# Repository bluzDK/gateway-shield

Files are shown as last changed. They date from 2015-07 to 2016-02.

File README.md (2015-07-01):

<p align="center" >
Bluz
</p>

Bluz Gateway Shield Hardware Files
==========
Bluz is a Development Kit (DK) that implements the Wiring language and talks to the [Particle](https://www.particle.io/) cloud through Bluetooth Low Energy. It can be accessed through a REST API and programmed from a Web IDE.

These files have been made available online through a [Creative Commons Attribution-ShareAlike 3.0](http://creativecommons.org/licenses/by-sa/3.0/) license.

You are welcome to distribute, remix, and use these files for commercial purposes. If you do so, please attribute the original design to Bluz both on the website and on the physical packaging of the product or in the instruction manual. All derivative works must be published under the same or a similar license.

All items are subject to change over time as the product is designed, so make sure you are always looking at the latest information by pulling often.

##Sections
<b>BOM</b>: Current Bill of Materials for the gateway shield.

<b>Datasheets</b>: Datasheets for all major parts on the board.

<b>HW Design</b>: Schematics, board layouts, and other design files.

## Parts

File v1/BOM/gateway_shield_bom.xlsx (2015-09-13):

Part(s) | Package | Value | Description | Qty | Manufacturer | Mfg. Part Number | Data Sheet | Notes
U2 | SMD |  | nrf51822 module with 32K RAM | 1 | Raytac | MDBT40 | data (http://www.raytac.com/download/MDBT40/MDBT40%20spec-Version%20M.pdf)
U1 | SOT-23 |  | Linear Regulator with 3.3V output | 1 | Microchip | MCP1825S-3302E/DB | data (http://www.microchip.com/mymicrochip/filehandler.aspx?ddocname=en531698)
U3 | SOIC-8 | 2Mb | 2Mb SPI Flash | 1 | Microcip | SST25VF020B-80-4I-SAE | data (http://ww1.microchip.com/downloads/en/DeviceDoc/20005054C.pdf)
U4 | Thru |  | 0.1" 12-pin female header | 2 |  | PPTC121LFBN-RC | data (http://www.sullinscorp.com/drawings/78_P(N)PxCxxxLFBN-RC,_10492-H.pdf)
Q1 | SMD | 32.768KHz | 20ppm, 9pF, 32.768KHz crystal | 1 |  | ABS06-32.768KHZ-9-T | data (http://www.abracon.com/Resonators/ABS06.pdf)
C1-C4 | 0603 | 0.1uF | 0603 Package | 4 |  | GRM188R71C104KA01D | data (http://search.murata.co.jp/Ceramy/image/img/A01X/partnumbering_e_01.pdf)
C7 | 0603 | 1uF | 0603 Package | 1 |  | CL10B105KP8NNNC | data (http://www.samsungsem.com/kr/front/downloadcms.do?fileName=S_CL10B105KP8NNNC.pdf)
C5, C6 | 0603 | 12pF | 0603 Package | 2 |  | CL10C120JB8NNNC | data (http://www.samsungsem.com/kr/front/downloadcms.do?fileName=S_CL10C120JB8NNNC.pdf)
R1, R2 | 0603 | 1K Ohm | 1k Ohm | 2 |  | CRCW06031K00FKEA | data (http://www.vishay.com/docs/20035/dcrcwe3.pdf)
L1 | 0603 |  | White SMD LED | 1 |  | LW Q38G-Q1S1-3K6L-1 | data (http://www.osram-os.com/Graphics/XPic6/00086183_0.pdf)
J1 | SMD |  | 0.05" 10-pin header | 1 |  | 20021121-00010C4LF | data (http://portal.fciconnect.com/Comergent/fci/drawing/20021121.pdf)
J2 | SMD |  | Micro USB Type B Female | 1 | FCI | 10118192-0001LF | data (http://portal.fciconnect.com/Comergent/fci/drawing/10118192.pdf)
S1 | SMD |  | 3.5mmx2.9mm Tactile Switch | 1 |  | EVP-AA202K | data (http://industrial.panasonic.com/www-data/pdf/ATK0000/ATK0000CE26.pdf)

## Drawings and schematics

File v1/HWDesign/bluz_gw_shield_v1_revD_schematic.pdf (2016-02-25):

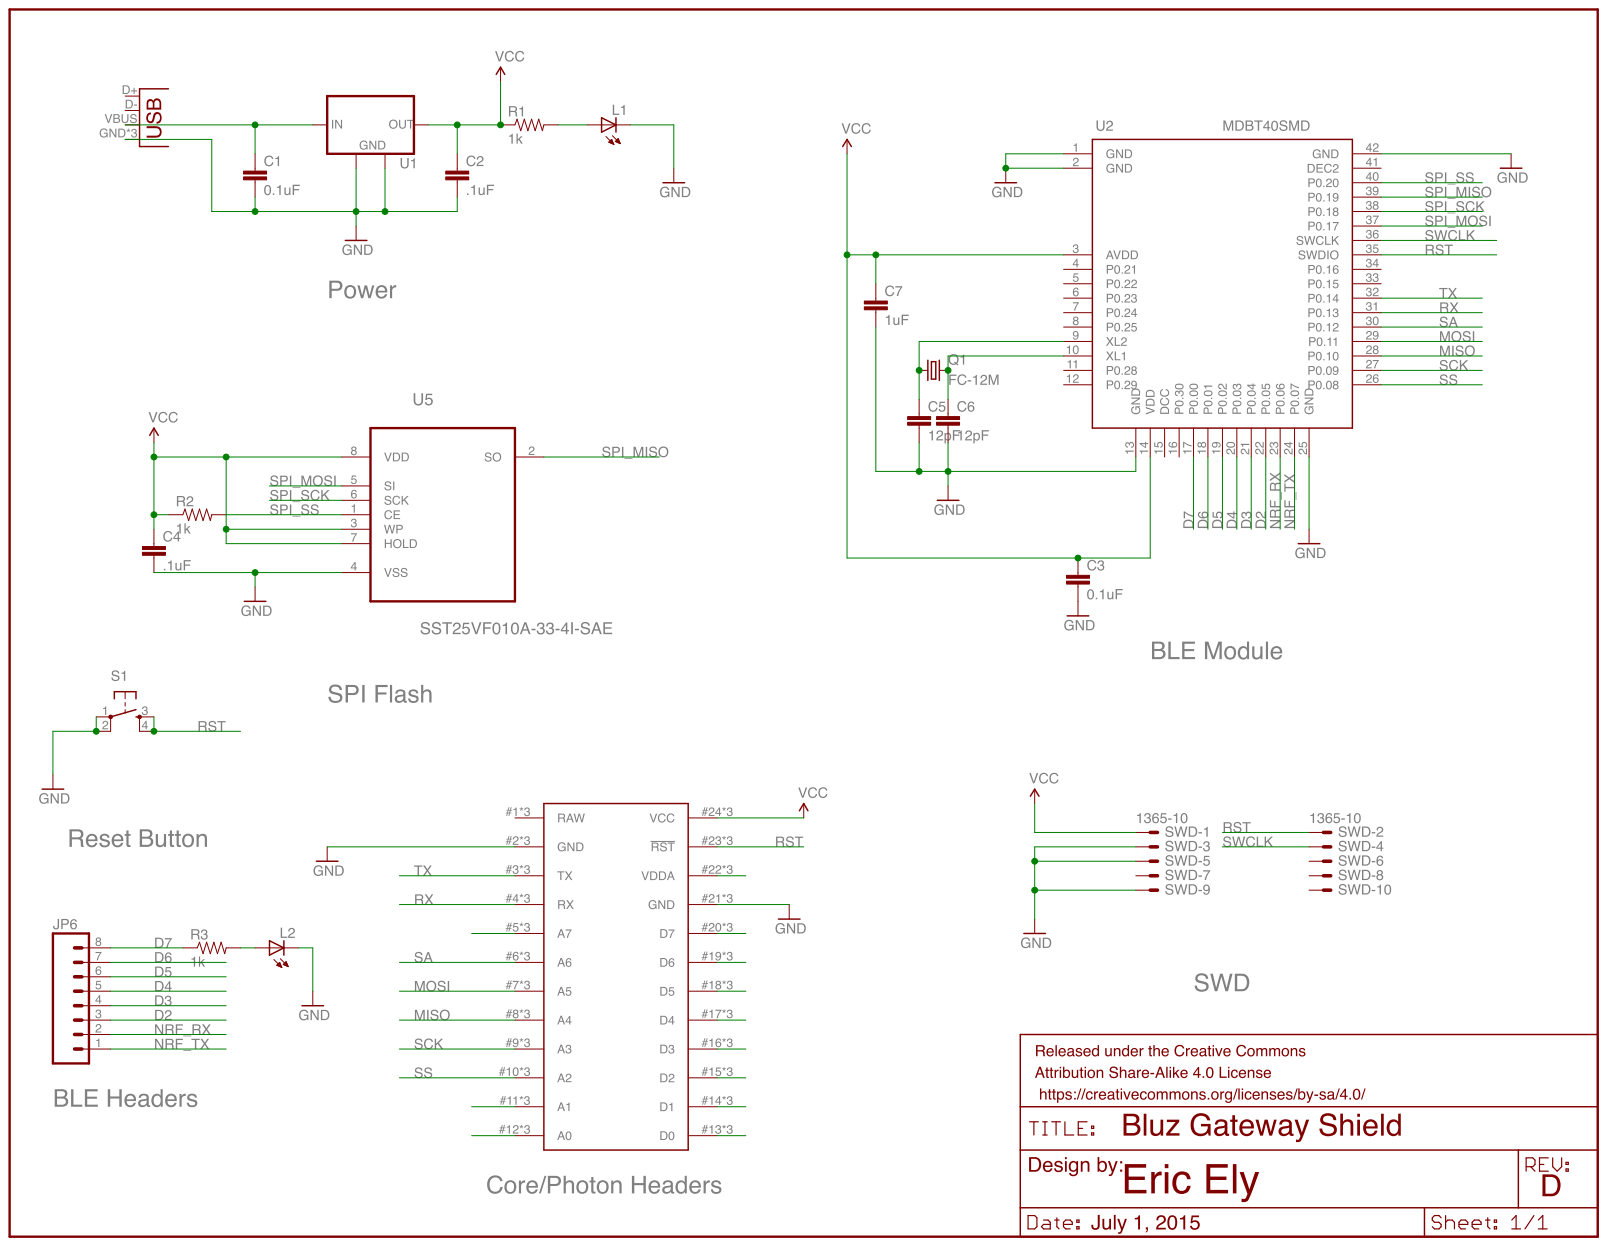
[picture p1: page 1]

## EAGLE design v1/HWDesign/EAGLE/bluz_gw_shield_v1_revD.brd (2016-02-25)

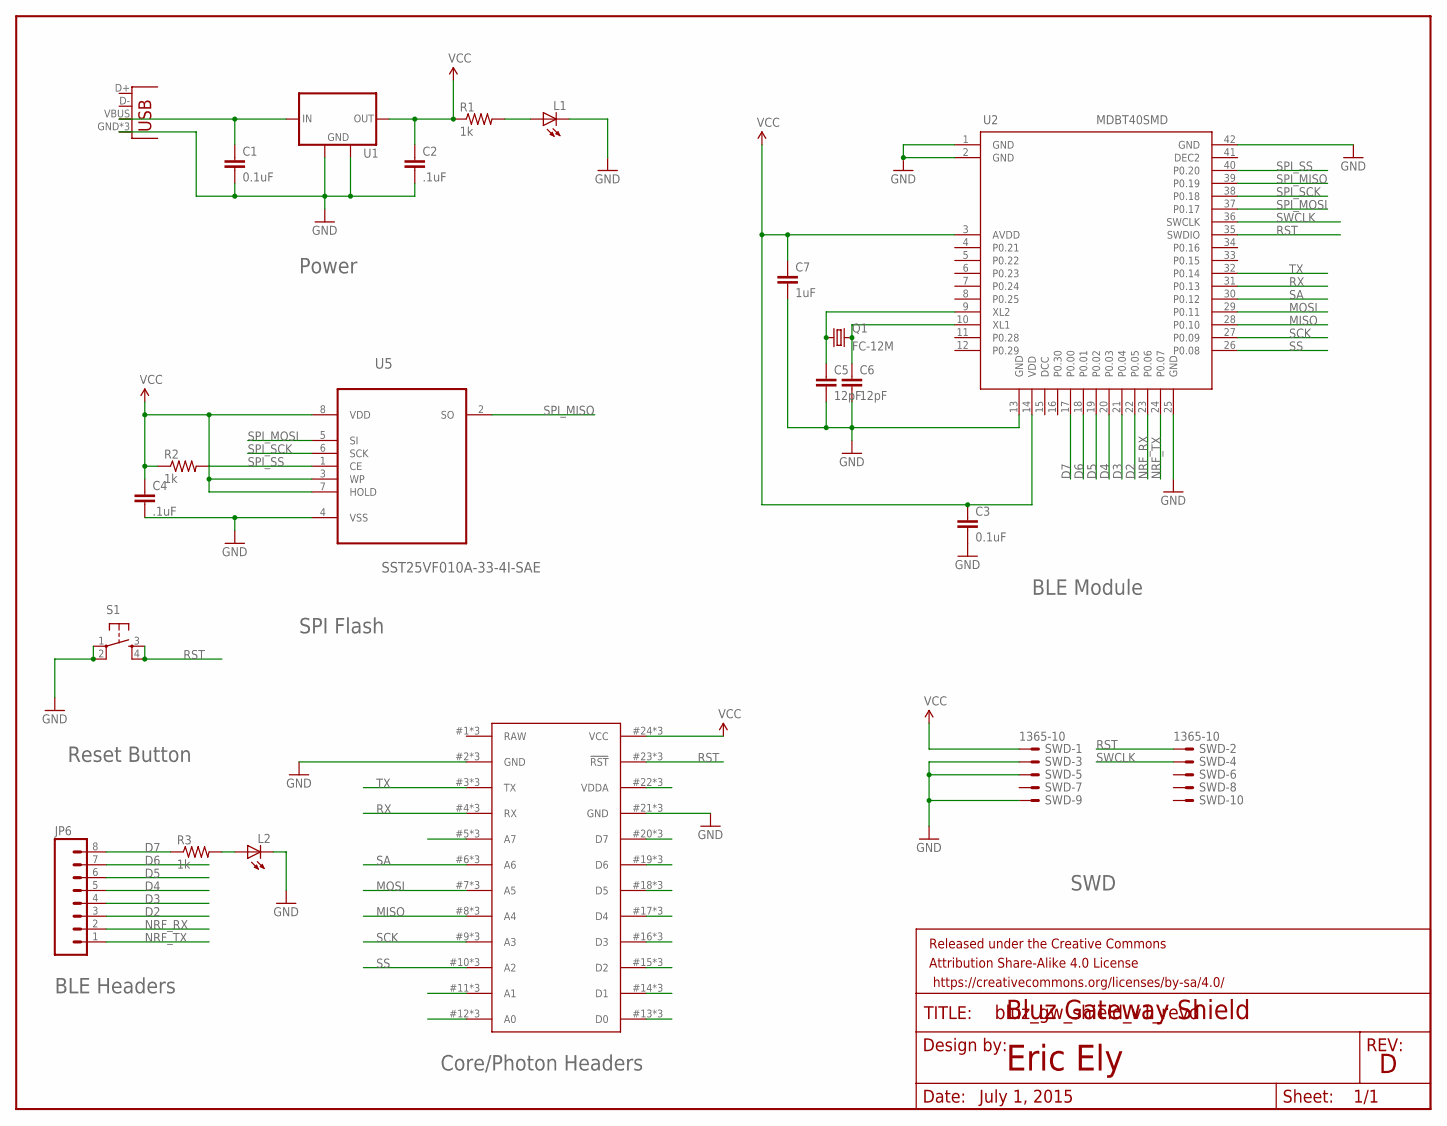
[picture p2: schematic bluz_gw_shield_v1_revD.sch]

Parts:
C1, C3: 0.1uF; 0603-CAP
C2, C4: .1uF; 0603-CAP
C5, C6: 12pF; 0603-CAP
C7: 1uF; 0603-CAP
FRAME1: FRAME-LETTER; CREATIVE_COMMONS
J2: USB-MICROB
JP6: M081X08; 1X08
L1, L2: LEDCHIP-LED0603; CHIP-LED0603
Q1: FC-12M
R1, R2, R3: 1k; 0603-RES
S1: TAC_SWITCHSMD; TACTILE_SWITCH_SMD
SWD: 1365-10
U1: MCP1825S-SOT223; SOT223
U2: MDBT40SMD; MDBT40
U4: SPARK_CORE; SPARK_CORE_STACKABLE
U5: SST25VF010A-33-4I-SAE; SOIC127P600X175-8N

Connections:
D2: JP6.3, U2.22 (P0.05)
D3: JP6.4, U2.21 (P0.04)
D4: JP6.5, U2.20 (P0.03)
D5: JP6.6, U2.19 (P0.02)
D6: JP6.7, U2.18 (P0.01)
D7: JP6.8, R3.1, U2.17 (P0.00)
GND: C1.2, C2.2, C3.2, C4.2, C5.2, C6.2, C7.2, J2.GND, J2.MT1 (GND), J2.MT2 (GND), L1.C, L2.C, S1.1, S1.2, SWD.3, SWD.5, SWD.9, U1.2 (GND), U1.4 (GND), U2.1 (GND), U2.2 (GND), U2.13 (GND), U2.25 (GND), U2.42 (GND), U4.2 (GND), U4.21 (GND), U4.#2 (GND), U4.#21 (GND), U4.@2 (GND), U4.@21 (GND), U5.4 (VSS)
MISO: U2.28 (P0.10), U4.8 (A4), U4.#8 (A4), U4.@8 (A4)
MOSI: U2.29 (P0.11), U4.7 (A5), U4.#7 (A5), U4.@7 (A5)
unnamed: C1.1, J2.VBUS, U1.1 (IN)
unnamed: L2.A, R3.2
unnamed: U4.5 (A7), U4.#5 (A7), U4.@5 (A7)
unnamed: U4.11 (A1), U4.#11 (A1), U4.@11 (A1)
unnamed: L1.A, R1.2
unnamed: U4.12 (A0), U4.#12 (A0), U4.@12 (A0)
unnamed: C5.1, Q1.1, U2.9 (XL2)
unnamed: C6.1, Q1.2, U2.10 (XL1)
unnamed: U4.13 (D0), U4.#13 (D0), U4.@13 (D0)
unnamed: U4.14 (D1), U4.#14 (D1), U4.@14 (D1)
unnamed: U4.15 (D2), U4.#15 (D2), U4.@15 (D2)
unnamed: U4.16 (D3), U4.#16 (D3), U4.@16 (D3)
unnamed: U4.17 (D4), U4.#17 (D4), U4.@17 (D4)
unnamed: U4.18 (D5), U4.#18 (D5), U4.@18 (D5)
unnamed: U4.19 (D6), U4.#19 (D6), U4.@19 (D6)
unnamed: U4.20 (D7), U4.#20 (D7), U4.@20 (D7)
unnamed: U4.22 (VDDA), U4.#22 (VDDA), U4.@22 (VDDA)
NRF_RX: JP6.2, U2.23 (P0.06)
NRF_TX: JP6.1, U2.24 (P0.07)
RAW: U4.1 (RAW), U4.#1 (RAW), U4.@1 (RAW)
RST: S1.3, S1.4, SWD.2, U2.35 (SWDIO), U4.23 (!RST), U4.#23 (!RST), U4.@23 (!RST)
RX: U2.31 (P0.13), U4.4 (RX), U4.#4 (RX), U4.@4 (RX)
SA: U2.30 (P0.12), U4.6 (A6), U4.#6 (A6), U4.@6 (A6)
SCK: U2.27 (P0.09), U4.9 (A3), U4.#9 (A3), U4.@9 (A3)
SPI_MISO: U2.39 (P0.19), U5.2 (SO)
SPI_MOSI: U2.37 (P0.17), U5.5 (SI)
SPI_SCK: U2.38 (P0.18), U5.6 (SCK)
SPI_SS: R2.2, U2.40 (P0.20), U5.1 (CE)
SS: U2.26 (P0.08), U4.10 (A2), U4.#10 (A2), U4.@10 (A2)
SWCLK: SWD.4, U2.36 (SWCLK)
TX: U2.32 (P0.14), U4.3 (TX), U4.#3 (TX), U4.@3 (TX)
VCC: C2.1, C3.1, C4.1, C7.1, R1.1, R2.1, SWD.1, U1.3 (OUT), U2.3 (AVDD), U2.14 (VDD), U4.24 (VCC), U4.#24 (VCC), U4.@24 (VCC), U5.3 (WP), U5.7 (HOLD), U5.8 (VDD)

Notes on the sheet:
Core/Photon Headers
Power
BLE Module
SWD
BLE Headers
Eric Ely
Bluz Gateway Shield
July 1, 2015
SPI Flash
Reset Button

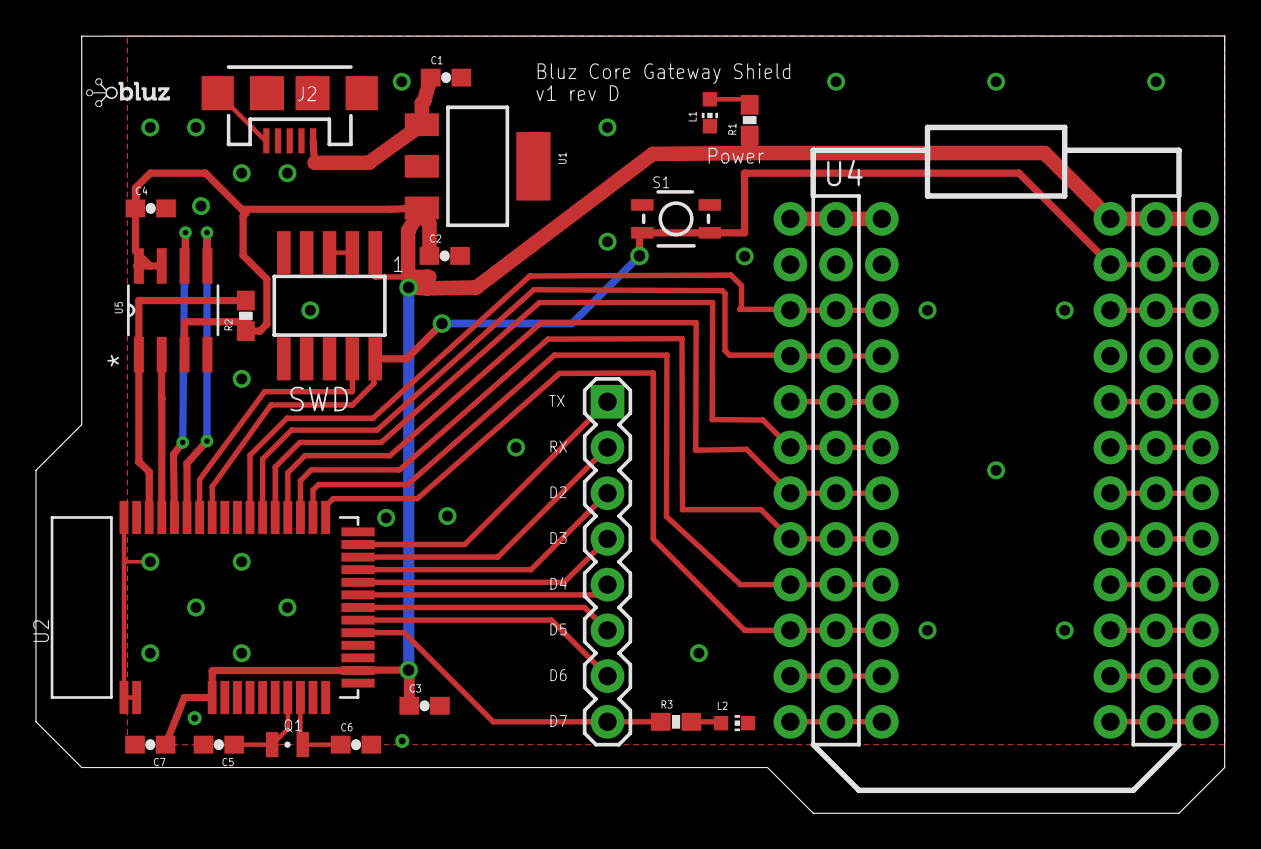
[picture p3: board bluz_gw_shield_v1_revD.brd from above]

Board: 2 copper layers, 66.0 x 43.2 mm, 23 parts (0 on the bottom side), 41 nets.

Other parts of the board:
U$2: BLUZE_LOGO_LOW_RES

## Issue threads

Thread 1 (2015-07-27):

Need Reset Button

eely22, 2015-07-27:
Need to have a reset button on the board to reset both the Particle board and the BLE module.

eely22, 2015-08-20:
Added in the latest commit.

Closed 2015-08-20.

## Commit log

2015-07-01 update BOM
    [gateway_shield_bom.xlsx]
2015-07-03 new schematic. eagle files
    [bluz_gw_shield_v1.brd, bluz_gw_shield_v1.sch]
2015-08-19 add reset button
    [bluz_gw_shield_v1.brd, bluz_gw_shield_v1.sch]
2015-09-13 updated BOM, was missing a few things
    [bluz_gw_shield_v1.brd, bluz_gw_shield_v1.sch, gateway_shield_bom.xlsx]
2016-02-25 newest files from adding the LED on D7 and TX/RX pins
    [bluz_gw_shield_v1_revD.brd, bluz_gw_shield_v1_revD.sch]

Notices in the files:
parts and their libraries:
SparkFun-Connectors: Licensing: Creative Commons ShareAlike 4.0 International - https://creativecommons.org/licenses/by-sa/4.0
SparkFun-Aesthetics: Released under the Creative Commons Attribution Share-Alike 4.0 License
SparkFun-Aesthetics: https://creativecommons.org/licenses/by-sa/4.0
